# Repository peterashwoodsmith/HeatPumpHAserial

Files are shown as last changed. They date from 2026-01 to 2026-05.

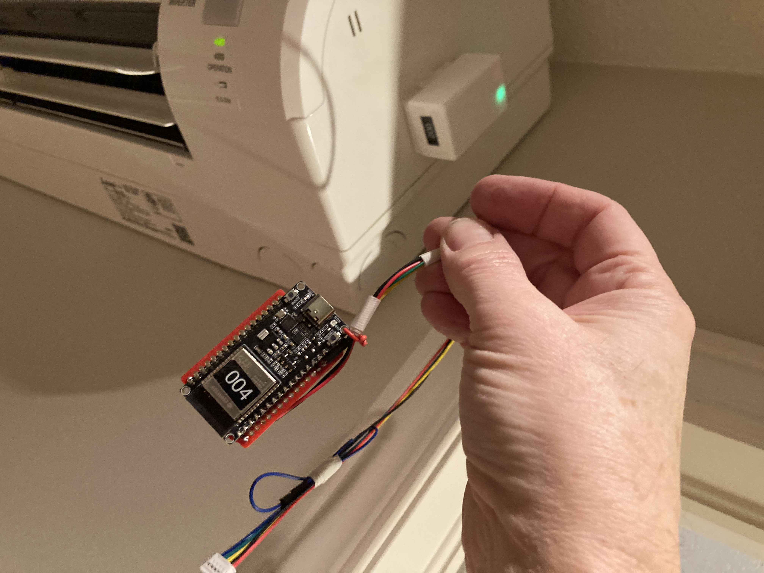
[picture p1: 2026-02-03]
IMG_4080.jpeg

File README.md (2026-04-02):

This is a Zigbee end point controller for a Mitsubishi Heat Pump via its CT105 serial port.
For full details on code/hardware see the HeatPumpHAserial.ino code. A simple wiring diagram 
is provided in Wiring.pdf however this is based on my heat pumps and I make no guarantee your
wiring will be the same so you must measure carefully to determine if this is appropriate for
your devices.

Included in this repository are HeatPump.cpp and HeatPump.h on which this code relies to provide the 
serial interface to the Heat Pump. This excellent piece of code is located in github along with other 
examples of its use. Link below:

https://github.com/SwiCago/HeatPump/tree/master  (c) 2017 Al Betschart
 
Also included are a trivial little box and lid that conveniently fit the hardware on the side
of the heat pump that you can 3d print or of course any plastic box of suitable dimensions would work.

Ive also added the YAML code for the dashboard that I used for a single device and its clusters.
Since the zigbee chosen icons etc. are not good this overwrites those defaults and creates an 'ok'
interface however much more could be done with a markup or something more flexible but there are 
only so many hours in a day.

If you are using Zigbee2MQTT an additional configuration file is included to help with the mappings
of the clusters. This is mitsubishi_hp.js and is provided with thanks to Martin P Dee. 

See the comments in the HeatPumpHAserial.ino for full details

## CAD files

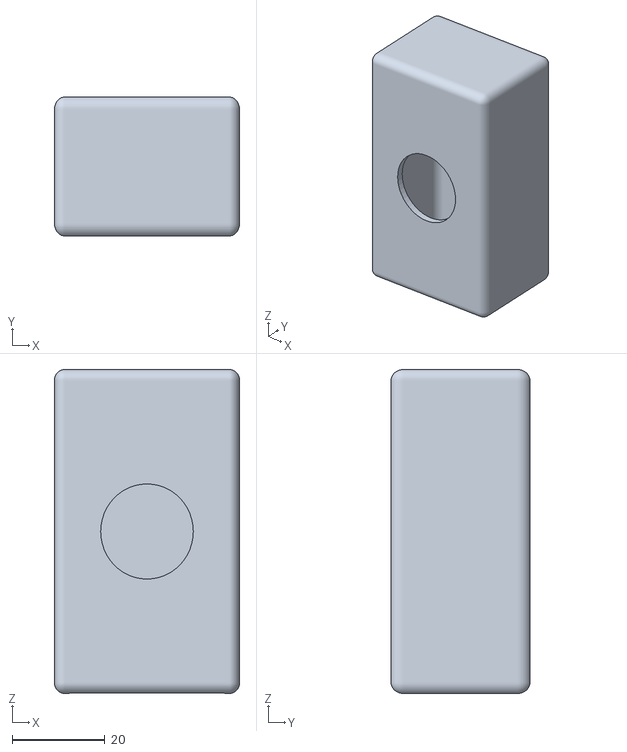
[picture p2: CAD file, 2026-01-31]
MitsubishiCase.stl
40.0 x 30.0 x 70.0

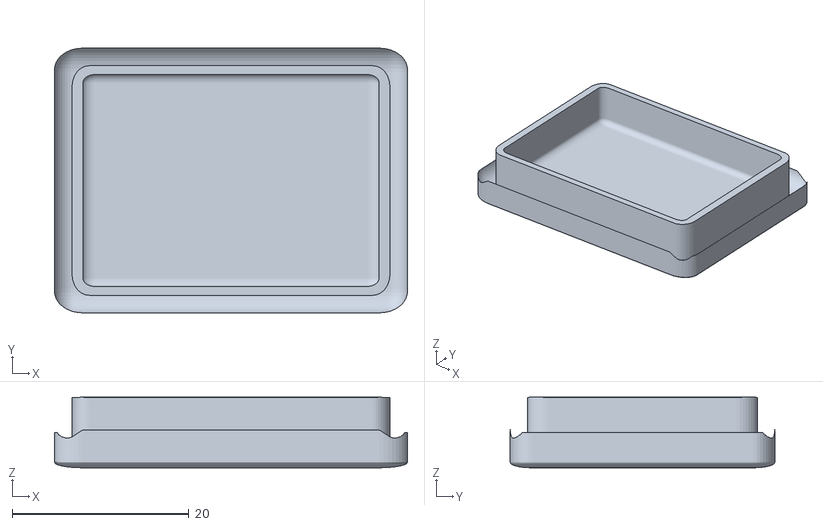
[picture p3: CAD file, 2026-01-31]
MitsubishiCaseTop.stl
40.0 x 30.0 x 8.00

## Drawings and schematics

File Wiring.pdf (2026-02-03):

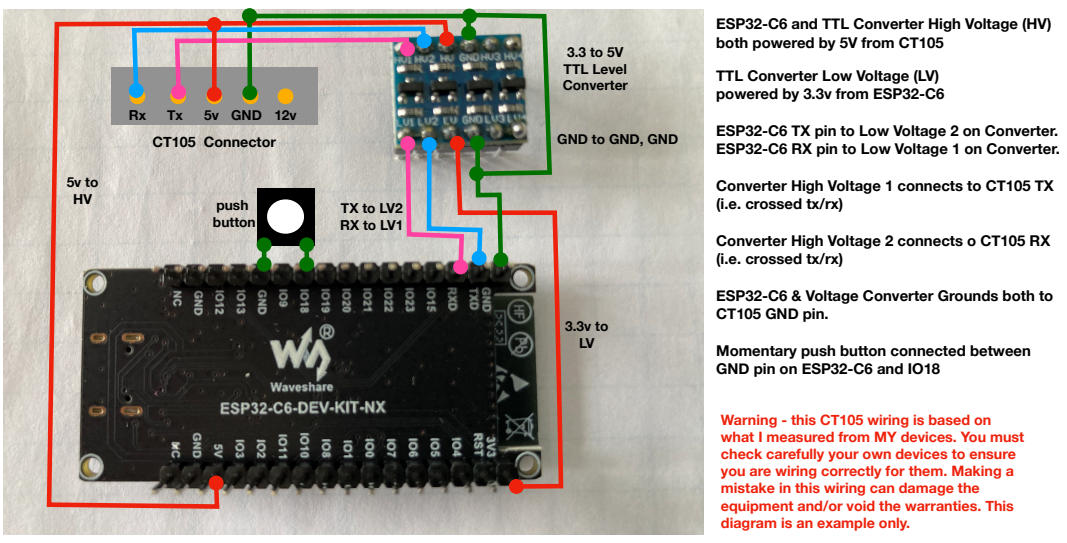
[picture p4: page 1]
3.3 to 5V TTL Level Converter; push button; CT105 Connector; 5v GND 12v

ESP32-C6 and TTL Converter High Voltage (HV)
both powered by 5V from CT105
TTL Converter Low Voltage (LV)
powered by 3.3v from ESP32-C6

ESP32-C6 TX pin to Low Voltage 2 on Converter.
ESP32-C6 RX pin to Low Voltage 1 on Converter.

GND to GND, GND

Converter High Voltage 1 connects to CT105 TX
(i.e. crossed tx/rx)

Converter High Voltage 2 connects o CT105 RX

ESP32-C6 & Voltage Converter Grounds both to
CT105 GND pin.

Momentary push button connected between
GND pin on ESP32-C6 and IO18

Warning - this CT105 wiring is based on
what I measured from MY devices. You must
check carefully your own devices to ensure
you are wiring correctly for them. Making a
mistake in this wiring can damage the
equipment and/or void the warranties. This
diagram is an example only.

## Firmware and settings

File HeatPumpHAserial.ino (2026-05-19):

//
// This ESP32 ARDUINO program is a Zibgee end device that will receive commands to be translated into serial for the 
// MISTUBISHI HEATE PUMP. THis is work in progress for a Home Assistant end point that you attach with the serial CT105 port
// on the heat pump.
//
// The code has two major parts. The first is the serial HeatPump object which comes from another author (see below).
// Following that is the zibgee 3.0 Espressif Arduino code to create the end points and their controls (clusters) that select
// the various parameters for the heat pump. 
//       
//     PARTA     https://github.com/SwiCago/HeatPump/tree/master,      (c) 2017 Al Betschart
//     PARTB     https://github.com/peterashwoodsmith/HeatPumpHA       (c) 2026 Peter Ashwood-Smith 
//
// HARDWARE:
//          Waveshare ESP32-C6 but should work on any ESP32 that supports Zibgee and has an RGB Led for status indication.
//          Push button for the reset option, any momentarily on push button will work.
//          Since the HeatPump uses 5V for its serial port and the ESP32 uses 3.3v a level shifter board with at least 
//          two channels are required. 
//
//          The level shifter board takes 5V and Ground on its High Voltage side and 3.3V and Ground on its low voltage
//          side. The Serial TX and RX are connected to two free pins on the low voltage side, i.e. LV1, LV2 while the
//          corresponding high voltage sides are connected to the CT105 corresponding pins for RX and TX (i.e. TX->RX).
//          Power from the CT105 (5V) can drive the 5V pin on the ESP32-C6 and of course CT105 ground pin to ESP32-C6 Ground.
//
//          The reset button is connected to GPIO18 and Ground, this is convenient because they are one pin separated
//          so you can just solder a reset button between them but any pin and ground should work. This is used to trigger a 
//          factory reset, for a normal reset just power cycle the board.
//
// BUILD NOTES:
//          I built this on a Mac and had problems with the USB driver. Waveshare has a nice page describing how to put a new
//          driver on your Mac which worked perfectly. Without it one of my boards refused to load the code via Arduino but 
//          surprise a bunch of other boards worked just fine. Anyway if you get CRC errors downlaoding, try lower speeds and if that
//          fails pop over to Waveshare and lookup the USB driver problem.
//
//          ARDUINO IDE TOOLS SETTINGS:
//          You need to set a number of settings in the Arduino IDE/Tools menu for this to work properly.
//              1 - Tools/USB CDC on boot - enabled (allows serial IO for debugging).
//              2 - Tools/Core debug level (set as desired useful for debugging zibbee attach etc.) start verbose.
//              3 - Tools/Erase all flash before upload - this means each download its a brand new Zibgee end point.
//                  Id erase for first few downloads and always delete/reattach but after its working don't erease the
//                  flash each time. Once its working you can erase the flash and start scratch with a long press on the
//                  reset button anyway.
//              3 - Tools/partition scheme: 4MB with spiffs - seems to be what the Zibgee library wants.
//              4 - Tools/zibgee mode ED (end device) - you can also use the end mode with debug enabled for more tracing.
//
// SOFTWARE:
//          There is a debug variable you can set 1/0 for serial I/O debugging. Start 1 turn off later.
//          On initial startup the code will start a watch dog timer just in case. This will cause a panic reset if the main
//          loop() is not entered frequently enough indicating something got stuck. The main loop() of course 'feeds' this watch
//          dog but only in the main work part of the loop with serial port connected and functioning.
//          Next we setup interrupt handlers for the reset button. Basically if reset is pressed we isue a reset to the ESP but we
//          also we erase the non volatile memory which will cause the end point to forget any ziggee related information and it
//          will have to rebind. If you do this you need to
//          delete the device from home assistant and go back into zigbee discover mode to refind this end point. For a normal
//          non factory reset just power cycle or use the ESP32 reset button.
//          We use the RGB Led to indicate whats going on. Red flashing as it first boots, orange as its getting ready to attach to the
//          zigbee network and then blue flashing as its trying to bind with the zibgee network and finally green flashing as its in the
//          main loop() waiting for HA to ask it to do something.
//          In the setup() code we will create the zibbee end points one for each of the clusters/attributes we want to control.
//          These are using the Espressif Arduino interface which is high level but not well documented. Essentially you create the
//          objects and a callback to set each parameter and then bind them to zibgee and wait for it to connect. After that its all
//          callbacks.
//          In the callbacks we just remember the attribute changes which are processed later in the main loop().
//          In the main loop we look for any attribute changes and if so call hp object to send the serial commands. 
//          Note that we also take setting changes from the heap pump and feed them back to zigbee by callback. That way if the
//          IR remove makes changes it shows up in the zibgee cluster correctly. Sadly there is no way for the zigbee changes to 
//          appear on the IR remote.
//
//  Home Assistant Notes:
//          As a Zibgee device you need to put the Zibgee in device search mode. If all goes well when the ESP32 boots it will flash 
//          red orange then blue and stay blue until you see Home Assistant show the device has connected etc. at which point it 
//          will flash green. Once its bound you can reset the ESP32 via power etc. and it will reattach fast and remember what ever
//          name you gave it. Initial binding can take a few minutes. Any problems just press to erase the NVS and delete the 
//          device from HA and go back into device discorvery on HA to let it rebind. Sometimes being close to the HA/Zibbee dongle
//          helps so if its cause problem, erase the NVS, delete the device from HA and move close to your dongle to retry. I suspect 
//          the dongles and HA notice devices trying to attach too frequently and back off a bit so sometimes waiting a few minutes to
//          retry gives you a quik attach.
// 
//  TODO:
//          
//
//  NOTES:
//          I make no claims that this even works, or that your entire house won't explode if you use it. Nobody should ever use this 
//          for anything serious ever. This is for educational purposes only. Serious harm could come to your expensive heat pump if any
//          miswiring, code failure, or other issues occur. 
//
//          Enjoy. Peter Ashwood-Smith and with thanks to Al Betschart for the superb HeatPump object code which worked perfectly first time
//          and I've not had to change a single line of code. I include it in the Git for this project for consistency in case his code 
//          changes in the future.
//
#include <esp_task_wdt.h>
#include <nvs_flash.h>
#include <freertos/FreeRTOS.h>
#ifndef ZIGBEE_MODE_ED
#error "Zigbee end device mode is not selected in Tools->Zigbee mode"
#endif
#include "Zigbee.h"
#include "HeatPump.h"
#include "esp_log.h"

//
// Output unitless count app type missing so define it.
//
#define ESP_ZB_ZCL_AO_COUNT_UNITLESS_COUNT  ESP_ZB_ZCL_AO_SET_APP_TYPE_WITH_ID( ESP_ZB_ZCL_AO_APP_TYPE_COUNT_UNITLESS, 0x0000)
//
// Debugging stuff, simple macro to log debug for us.
//
static const char *TAG = "HP2ZS"; 
#define DPRINTF(format, ...)  ESP_LOGD(TAG, format, ##__VA_ARGS__) 

//
// Set 1 and you'll get lots of useful info as it runs. For debugging the lower layer Zibgee see the tools settings
// in the Arduino menu for use with the debug enabled library and debug levels in that core. We can also compile in/out 
// the watch dog timers. 
//
const bool debug_g = false;
const bool wdt_g   = true;

// 
// Non volatile storage for debugging. When we restart etc. we will write the reasons 
// and track last uptime etc. for display via a Zigbee debug cluster sensor.
//
const char       *ha_nvs_name = "_HP2MIS_";                // Unique name for our partition
const char       *ha_nvs_vname= "_vars_";                  // name for our packeed variables
nvs_handle_t      ha_nvs_handle = 0;                       // Once open this is read/write to NVS
uint32_t          ha_nvs_last_uptime = 0;                  // minutes we were up last time before reboot
uint32_t          ha_nvs_last_reboot_reason = 0;           // why we rebooted last time. (0 factory reset)
uint32_t          ha_nvs_last_reboot_count = 0;            // increase each reboot except factory reset

//
// We are looking for persistant values of the last reboot reason and last uptime. We store these two packed
// into a single Uint32 which we depack after reading from the NVS.
//
void ha_nvs_read()
{    
     ha_nvs_last_reboot_reason = 0;
     ha_nvs_last_uptime        = 0;
     ha_nvs_last_reboot_count  = 0;
     //
     esp_err_t err = nvs_flash_init();
     if (err == ESP_ERR_NVS_NO_FREE_PAGES || err == ESP_ERR_NVS_NEW_VERSION_FOUND) {
        // NVS partition was truncated and needs to be erased
        nvs_flash_erase();
        nvs_flash_init();
        if (debug_g) DPRINTF("ha_nvs_read - nvs_flash_init\n", esp_err_to_name(err));
     }
     err = nvs_open(ha_nvs_name, NVS_READWRITE, &ha_nvs_handle);
     if (err != ESP_OK) {
        if (debug_g) DPRINTF("ha_nvs_read - Error (%s) opening NVS name %s!\n", esp_err_to_name(err), ha_nvs_name);
        return;
     }  
     //
     uint32_t vars;
     err = nvs_get_u32(ha_nvs_handle, ha_nvs_vname, &vars);
     if (err != ESP_OK) {
          if (debug_g) DPRINTF("ha_nvs_read - cant get variable name %s\n", ha_nvs_name);
          return;
     }
     ha_nvs_last_reboot_reason  = vars         & 0xff;
     ha_nvs_last_reboot_count   = (vars >> 8)  & 0xff;
     ha_nvs_last_uptime         = (vars >> 16) & 0xffff;
     ha_nvs_last_reboot_reason += esp_reset_reason() * 1000;  // See below for why * 1000
     /* 
      * For convenient reference. We multiply these by 1000 to we can see the 
      * ESPs idea why it rebooted together with our own reboot reason as a single
      * number displayed as a Zigbee cluster. This is taken from the enum so they 
      * start at 0,1,2... 
      *
      * ESP_RST_UNKNOWN,    //!< Reset reason can not be determined
      * ESP_RST_POWERON,    //!< Reset due to power-on event
      * ESP_RST_EXT,        //!< Reset by external pin (not applicable for ESP32)
      * ESP_RST_SW,         //!< Software reset via esp_restart
      * ESP_RST_PANIC,      //!< Software reset due to exception/panic
      * ESP_RST_INT_WDT,    //!< Reset (software or hardware) due to interrupt watchdog
      * ESP_RST_TASK_WDT,   //!< Reset due to task watchdog
      * ESP_RST_WDT,        //!< Reset due to other watchdogs
      * ESP_RST_DEEPSLEEP,  //!< Reset after exiting deep sleep mode
      * ESP_RST_BROWNOUT,   //!< Brownout reset (software or hardware)
      * ESP_RST_SDIO,       //!< Reset over SDIO
      * ESP_RST_USB,        //!< Reset by USB peripheral
      * ESP_RST_JTAG,       //!< Reset by JTAG
      * ESP_RST_EFUSE,      //!< Reset due to efuse error
      * ESP_RST_PWR_GLITCH, //!< Reset due to power glitch detected
      * ESP_RST_CPU_LOCKUP, //!< Reset due to CPU lock up (double exception)
      */
     if (debug_g) {
          DPRINTF("ha_nvs_read got vars=%x, reason %d, count %d, uptime=%d\n", vars,
               ha_nvs_last_reboot_reason, ha_nvs_last_reboot_count, ha_nvs_last_uptime);
     }
}

//
// And here is the write to NVS of the attributes after they have been changed and sent to the Heat Pump
//
void ha_nvs_write(uint32_t reason = 0, uint32_t uptime = 0)
{
     ha_nvs_last_reboot_count = (ha_nvs_last_reboot_count + 1) & 0xff;
     reason &= 0xff;
     uptime &= 0x0000fffff;
     uint32_t vars  = reason | (ha_nvs_last_reboot_count << 8) | (uptime << 16);
     if (debug_g) {
          DPRINTF("ha_nvs_write got vars=%x, reason %d, count %d, uptime=%d\n", vars, reason, ha_nvs_last_reboot_count, uptime);
     }
     esp_err_t err = nvs_set_u32(ha_nvs_handle, ha_nvs_vname, vars);
     if (err != ESP_OK) {
         if (debug_g) DPRINTF("ha_nvs_write  %s can't write, because %s\n", ha_nvs_vname, esp_err_to_name(err));
         return;
     }
     err = nvs_commit(ha_nvs_handle);
     if (err != ESP_OK) {
         if (debug_g) DPRINTF("ha_nvs_write %s can't commit, because %s\n", ha_nvs_vname, esp_err_to_name(err));
     }  
}
// 
// Function complete shutdown and restart. Forward declared also a flash sequence for factory reset.
//
extern void ha_restart(uint32_t reason, uint32_t uptime); 
extern void rgb_led_set_factory_reset();

//
// Interrupt handler for Reset button. If its pressed we do full factory reset. Normal reset is just done with a power off/on.
//
void isr_resetButtonPress()
{      
     rgb_led_set_factory_reset();                       // Go white so its obvious
     Zigbee.factoryReset(false);                        // This should do the same but not sure it does anyway ...
     ha_restart(0, 0);                                  // And stop all the Zigbee stuff and just restart the ESP
}

//
// Setup the Interrupt service routine for the reset button. Just call the isr_resetButtonPress routing when the pin goes LOW.
// This triggers a factory reset.
//
void isr_setup()
{    const unsigned int isr_resetButton = 18;               // We use pin 18 connected to one side of button, and ground to other side.   
     pinMode(isr_resetButton, INPUT_PULLUP);                // Pullup so GROUNDing cause FALLING and ungrounding causes RISING interrupts.
     //
     attachInterrupt(digitalPinToInterrupt(isr_resetButton), isr_resetButtonPress,   FALLING);  
}

//
// If the task watch dog times out, rather than use the system handler it will come here and we do a nice
// controlled reboot and keep track of the reason and how long we were up for better debugging.
//
void esp_task_wdt_isr_user_handler(void)
{
     ha_restart(1, millis()/1000); 
}

//
// Serial Interface libarary to the Heat Pump. The hp_send.. function just translates between the zigbee values for the various clusters and what
// the HeatPump methods take. Sadly its not that consistent because the Zigbee code only seems to be easy to do with numbers and not enumerated types.
// Converting the zibgee clusters to proper enumerations is FFS.
//
HeatPump hp;

void hp_sendHvacMitsubishi(
     int HVAC_Mode,            
     int HVAC_Temp,            
     int HVAC_FanMode,         
     int HVAC_VaneMode,        
     int HVAC_powerOff         
)
{    char *s;
     char power[10];
     strcpy(power, HVAC_powerOff ? "OFF" : "ON"); 
     //
     char mode[10];
     strcpy(mode, HVAC_Mode ? "HEAT" : "COOL");
     //
     int temp = HVAC_Temp;
     if (temp < 16) temp = 16;
     if (temp > 31) temp = 31;
     //
     char fan[10]; 
     switch(HVAC_FanMode){
          case  0: s = "QUIET"; break;
          case  1: s = "1";     break;
          case  2: s = "2";     break;
          case  3: s = "3";     break;
          case  4: s = "4";     break;
          default: s = "AUTO";  break;
     }
     strcpy(fan, s);
     //
     char vane[10];
     switch(HVAC_VaneMode){
          case  0: s = "AUTO"; break;
          case  1: s = "1";     break;
          case  2: s = "2";     break;
          case  3: s = "3";     break;
          case  4: s = "4";     break;
          case  5: s = "5";     break;   
          default: s = "SWING"; break;
     }
     strcpy(vane, s);//
     //
     heatpumpSettings settings = {
            power,   /* ON/OFF */
            mode,    /* HEAT/COOL/FAN/DRY/AUTO */
            temp,    /* Between 16 and 31 */
            fan,     /* Fan speed: 1-4, AUTO, or QUIET */
            vane,    /* Air direction (vertical): 1-5, SWING, or AUTO */
            "|"      /* Air direction (horizontal): <<, <, |, >, >>, <>, or SWING */
     };
     //
     // And set the desired settings and request an update to the HP.
     // Avoid doing this if we are not connected.
     //
     if (hp.isConnected()) {
         hp.setSettings(settings);
         hp.update();
     }
}

//
// Connect to the heat pump over serial port. We will install the callbacks for status changes. We
// Use the enable external updates so that changes made by the remove will show up in the zibgre 
// values in home assistant.
//
void hp_setup() {
     extern void hp_settingsChangedCallback();
     extern void hp_statusChangedCallback(heatpumpStatus);
     hp.enableExternalUpdate();
     hp.setSettingsChangedCallback(hp_settingsChangedCallback);
     hp.setStatusChangedCallback(hp_statusChangedCallback);
     hp.connect(&Serial1, 2400, 17, 16);
}

//
// PART B - Z I G B E E / Home Assistant interface
//

// 
// These are the EP control entities each has one cluser which is a 'knob' that controls an HVAC parameter
//
ZigbeeBinary      zbPower       = ZigbeeBinary(10);      // Power on/off knob
ZigbeeBinary      zbColdHot     = ZigbeeBinary(11);      // Heat or cooling knob
ZigbeeAnalog      zbTemp        = ZigbeeAnalog(12);      // Desired temperature slider
ZigbeeAnalog      zbFanControl  = ZigbeeAnalog(13);      // How the fans operate slider
ZigbeeAnalog      zbVaneControl = ZigbeeAnalog(14);      // Van motion/positions slider
//                                                     
// These are the EP sensors clusters. 
//
ZigbeeBinary      zbSerial      = ZigbeeBinary(15);      // Serial connection status
ZigbeeBinary      zbOperating   = ZigbeeBinary(16);      // HP working to get desired temperature
ZigbeeAnalog      zbRoomTemp    = ZigbeeAnalog(17);      // Temperature of room as seen by HP
//
ZigbeeAnalog      zbRebootReason= ZigbeeAnalog(18);      // reason for last reboot
ZigbeeAnalog      zbLastUptime  = ZigbeeAnalog(19);      // How long it was up last time before reboot
ZigbeeAnalog      zbRebootCount = ZigbeeAnalog(20);      // How many reboots since factory reset
ZigbeeAnalog      zbUptime      = ZigbeeAnalog(21);      // Seconds since last reboot.
//
// These are the variables that maintain the state of what HA has asked to be set
// set.
//
bool              ha_powerStatus   = 0;    // powered on/off
bool              ha_coldHotStatus = 0;    // heating or cooling mode
unsigned int      ha_fanStatus     = 0;    // fan position or movement
unsigned int      ha_tempStatus    = 0;    // desired temperature
unsigned int      ha_vaneStatus    = 0;    // how the vanes move or don't
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
void loop()
{    static int ix = 0;            // Loop counter 0..4 for LED on/of flash choice.
     //
     if (debug_g) DPRINTF("loop()\n");
     //
     if (!Zigbee.connected()) {
         if (debug_g) DPRINTF("zigbee disconnected while in loop()- restarting\n");
         ha_restart(5, millis()/1000);   
     }
     //
     // if we have comms with heat pump sync anything to/from the heat pump and feed the watch
     // dog. Otherwise don't feed watch dog. We can stay up and run for 10 minutes to play with
     // zibgee stuff but we'll get restarted to try to reestablish serial comms.
     //
     //
     int status_color = RGB_LED_WHITE;
     if (hp.isConnected()) {
         if (debug_g) DPRINTF("loop - hp.sync\n");
         hp.sync();
         status_color = RGB_LED_GREEN;
         //
         // And feed the watch dog because all is well, zigbee ok and serial comms ok.
         // 
         if (wdt_g) esp_task_wdt_reset();         
     } 
     //
     // Every so often (5 mins) we update the connected state to Home Assistant. Or if the
     // connected state changes update immediately. Hopefully this keeps the end point alive.
     //
     {  const unsigned long  MAX_TIME           = 60*5;
        static unsigned long last_update_time   = 0;
        static bool          last_updated_state = false;
        unsigned long        now_time           = millis() / 1000;
        bool                 now_state          = hp.isConnected();
        //
        if ((now_state != last_updated_state) || ((last_update_time + MAX_TIME) <= now_time)) {
            if (debug_g) DPRINTF("loop - issue connected cluster update %ld %d %ld %d\n", 
                                            last_update_time, last_updated_state, now_time, now_state);
            zbSerial.setBinaryInput(now_state);
            zbSerial.reportBinaryInput();
            last_update_time   = now_time;
            last_updated_state = now_state;
            ha_sync_nvs_clusters();            // Debug stuff
        }
     }
     //
     // Alternate GREEN|WHITE/BLACK every loop instance. This is green for one second every 10 seconds or so means all good.
     // If we get WHITE it means zigbee is up but serial is not connected.
     //
     rgb_led_set(ix != 0 ? RGB_LED_OFF : status_color);
     ix = (ix + 1) % 5;
     // 
     // Do any pending work for about a second if there is some.
     //
     ha_processPending();
     //
     // No need to buzz this loop, little pause is fine.
     //
     delay(1000);
}

/*
   Cluster ID 0x0202 Identifier: 0x0000 -   Value 00 = off, 1 = low, 2=med, 3=high, 4=on, 5=auto, 6=smart   
*/

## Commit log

2026-01-13 First attempt at Zibgee to Serial for Mitsubishi Heat Pump
2026-01-16 disable watch dog its causing problems.
    [HeatPumpHAserial.ino]
2026-01-16 adding a few sensor clusters
2026-01-17 Watch dog only fed when serial/zigbee are up.
    testing watch dog failures and restart. So allow it to stay up zigbeee only if no serial comms working.
    Watch dog will kill it and restart 10 minutes later if serial fails or is not connected.
    [HeatPumpHAserial.ino]
2026-01-18 fixing the NVS stuff (partition name was too long)
    And debug stuff using ESP_ rather than Serial.prin..
    [HeatPumpHAserial.ino]
2026-01-21 This is the version deployed on my heat pumps as of Jan 21/2026
    [MitsubishiCase.stl]
2026-01-31 file should not be here
    Remove extensive comments and documentation from the HeatPumpHA.ino file to streamline the code.
2026-01-31 Refine comments and fix typos in HeatPumpHAserial.ino
    Updated comments for clarity and corrected minor typos throughout the code.
    [HeatPumpHAserial.ino]
2026-01-31 Simple 3d printed cap for the box
    [MitsubishiCaseTop.stl]
2026-01-31 Case for the controller that sits on side of HP
    [MitsubishiCase.stl]
2026-01-31 Add Living Room configuration YAML example
    I name each new device 001..002..003 etc. so that the entity
    names are nice and unique to the device.
    Anyway this shows the icons/hidden stuff that I found useful.
    Note the double click to change heat mode from heat to cool etc. since its a major change.
2026-02-03 Simple wiring diagram
2026-02-03 Enhance README with wiring and dashboard details
    Updated README to include wiring diagram details and YAML code explanation.
2026-03-09 Fix type that causes problems with remote synch in cool mode
    "COLD" should be "COOL"
    [HeatPumpHAserial.ino]
2026-04-02 Update to include missing link to the git for HeatPump object
    Added link to the heat pump object
2026-05-17 Any remote set mode not COOL/HEAT shows as OFF
2026-05-19 Fix cooling mode synch , not displaying properly due to "COLD" rather than "COOL" check
    [HeatPumpHAserial.ino]
